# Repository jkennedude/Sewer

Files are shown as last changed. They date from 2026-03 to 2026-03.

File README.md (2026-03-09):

# Sewer
A guitar effects pedal, based on the Proco-Rat, with custom mods for use with Bass and noise reduction

Version 2 makes some incremental improvements:
- SMD Layout for most of the board
- Mix knob converted to additive opamp clean blend for ease of use and to prevent volume drop when turning up clean mix
- Bass Switch simplified and made internal
- Better fit and finish

Specifications:
- Designed for a Hammond 125B enclosure with top mounted jacks
- Power: 9V DC center negative, no battery support
- Support for external bypass board enabling true or buffered bypass
- Input impedance: 1MOhms or more
- Output impedance: ~1KOhm
- Buffered clean blend
- Switchable distortion bass boost changes how much bass is distorted
- Swichable clipping diodes (by default either standard 1N914 or turbo-rat style red LEDs)

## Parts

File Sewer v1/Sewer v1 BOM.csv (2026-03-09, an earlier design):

Id | Designator | Footprint | Quantity | Designation | Supplier and ref | Column1 | _1
1 | R_CLR | RES_0.25watt_L3.6mm_D1.6mm_P7.62mm_Horizontal | 1 | 4.7k
2 | R103,R102,R9,R1 | RES_0.25watt_L3.6mm_D1.6mm_P7.62mm_Horizontal | 4 | 1M
3 | D3,D4 | LED_D3.0mm | 2 | LED
4 | D2,D1 | D_DO-35_SOD27_P7.62mm_Horizontal | 2 | 1N914
5 | R10,R104,R105 | RES_0.25watt_L3.6mm_D1.6mm_P7.62mm_Horizontal | 3 | 10k
6 | C9 | C_Rect_L7.2mm_W2.5mm_P5.00mm_FKS2_FKP2_MKS2_MKP2 | 1 | 3n3
7 | C10,C1 | C_Rect_L7.2mm_W2.5mm_P5.00mm_FKS2_FKP2_MKS2_MKP2 | 2 | 22n
8 | R8 | RES_0.25watt_L3.6mm_D1.6mm_P7.62mm_Horizontal | 1 | 1k5
9 | Q102,Q101,Q1 | SOT-23_Handsoldering | 3 | J201
10 | C11 | C_Rect_L7.2mm_W7.2mm_P5.00mm_FKS2_FKP2_MKS2_MKP2 | 1 | 1u
11 | R2,R7 | RES_0.25watt_L3.6mm_D1.6mm_P7.62mm_Horizontal | 2 | 1k
12 | U1 | DIP-8_W7.62mm | 1 | OP07
13 | RV2 | POT_16MM | 1 | DIST A100k
14 | RV3 | POT_16MM | 1 | TONE A100k
15 | RV4 | POT_16MM | 1 | VOLUME A100k
16 | RV1 | POT_16MM | 1 | BLEND B100k
17 | SW1 | DPDT.LUGS | 1 | SW_DPDT_x2
18 | C203 | CP_Radial_D5.0mm_P2.50mm | 1 | 47u
19 | R6 | RES_0.25watt_L3.6mm_D1.6mm_P7.62mm_Horizontal | 1 | 270R
20 | C102,C202 | C_Rect_L7.2mm_W2.5mm_P5.00mm_FKS2_FKP2_MKS2_MKP2 | 2 | 100n
21 | C4 | CP_Radial_D5.0mm_P2.00mm | 1 | 2u2
22 | J2,J1 | SolderWire-0.25sqmm_1x04_P4.2mm_D0.65mm_OD1.7mm | 2 | Conn_01x04
23 | C3 | C_CERAMIC_DISC_D3.0mm_W1.6mm_P2.50mm | 1 | 100p
24 | R3,R201 | RES_0.25watt_L3.6mm_D1.6mm_P7.62mm_Horizontal | 2 | 47R
25 | R4,R5 | RES_0.25watt_L3.6mm_D1.6mm_P7.62mm_Horizontal | 2 | 560R
26 | R101 | RES_0.25watt_L3.6mm_D1.6mm_P7.62mm_Horizontal | 1 | 10M
27 | C7 | CP_Radial_D5.0mm_P2.50mm | 1 | 10u
28 | C2 | C_Rect_L7.2mm_W2.5mm_P5.00mm_FKS2_FKP2_MKS2_MKP2 | 1 | 1n
29 | C6,C8,C5 | CP_Radial_D5.0mm_P2.00mm | 3 | 4u7
30 | C101 | C_Rect_L7.2mm_W4.5mm_P5.00mm_FKS2_FKP2_MKS2_MKP2 | 1 | 470n
31 | C201 | CP_Radial_D5.0mm_P2.50mm | 1 | 100u
32 | R202,R203 | RES_0.25watt_L3.6mm_D1.6mm_P7.62mm_Horizontal | 2 | 100k
33 | SW2 | SW_SPDT | 1 | SW_SPDT

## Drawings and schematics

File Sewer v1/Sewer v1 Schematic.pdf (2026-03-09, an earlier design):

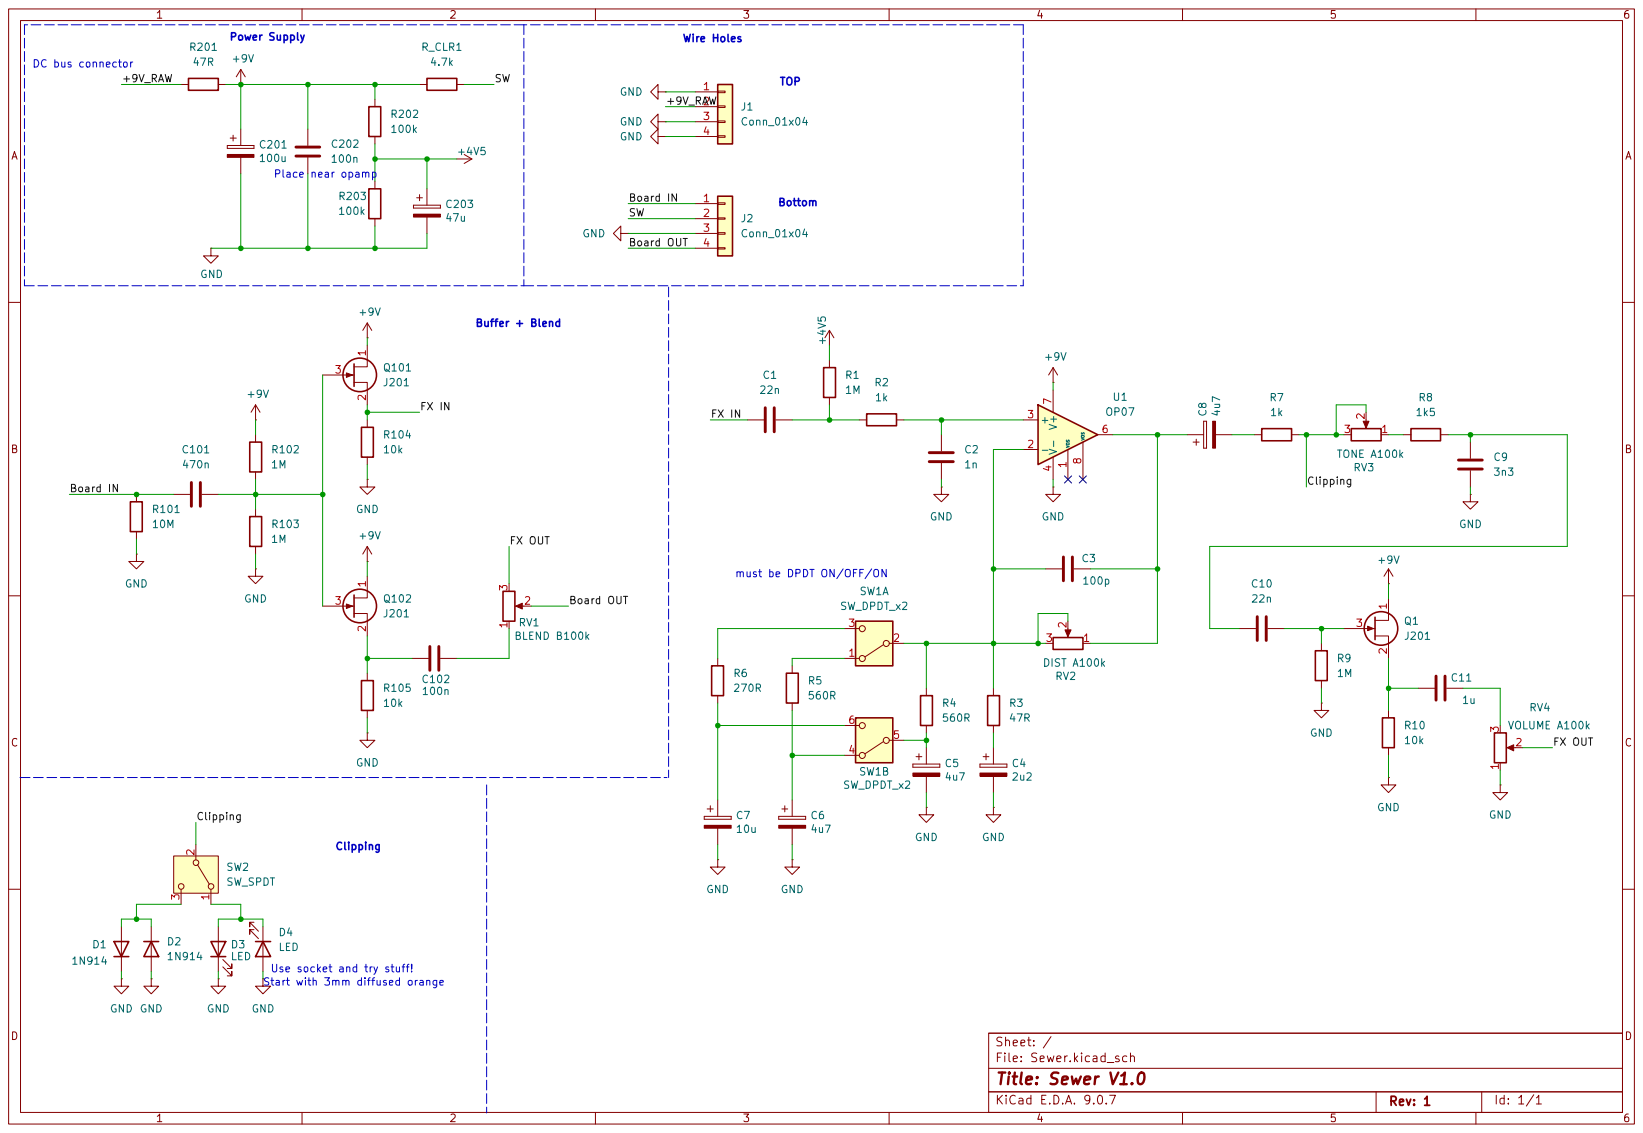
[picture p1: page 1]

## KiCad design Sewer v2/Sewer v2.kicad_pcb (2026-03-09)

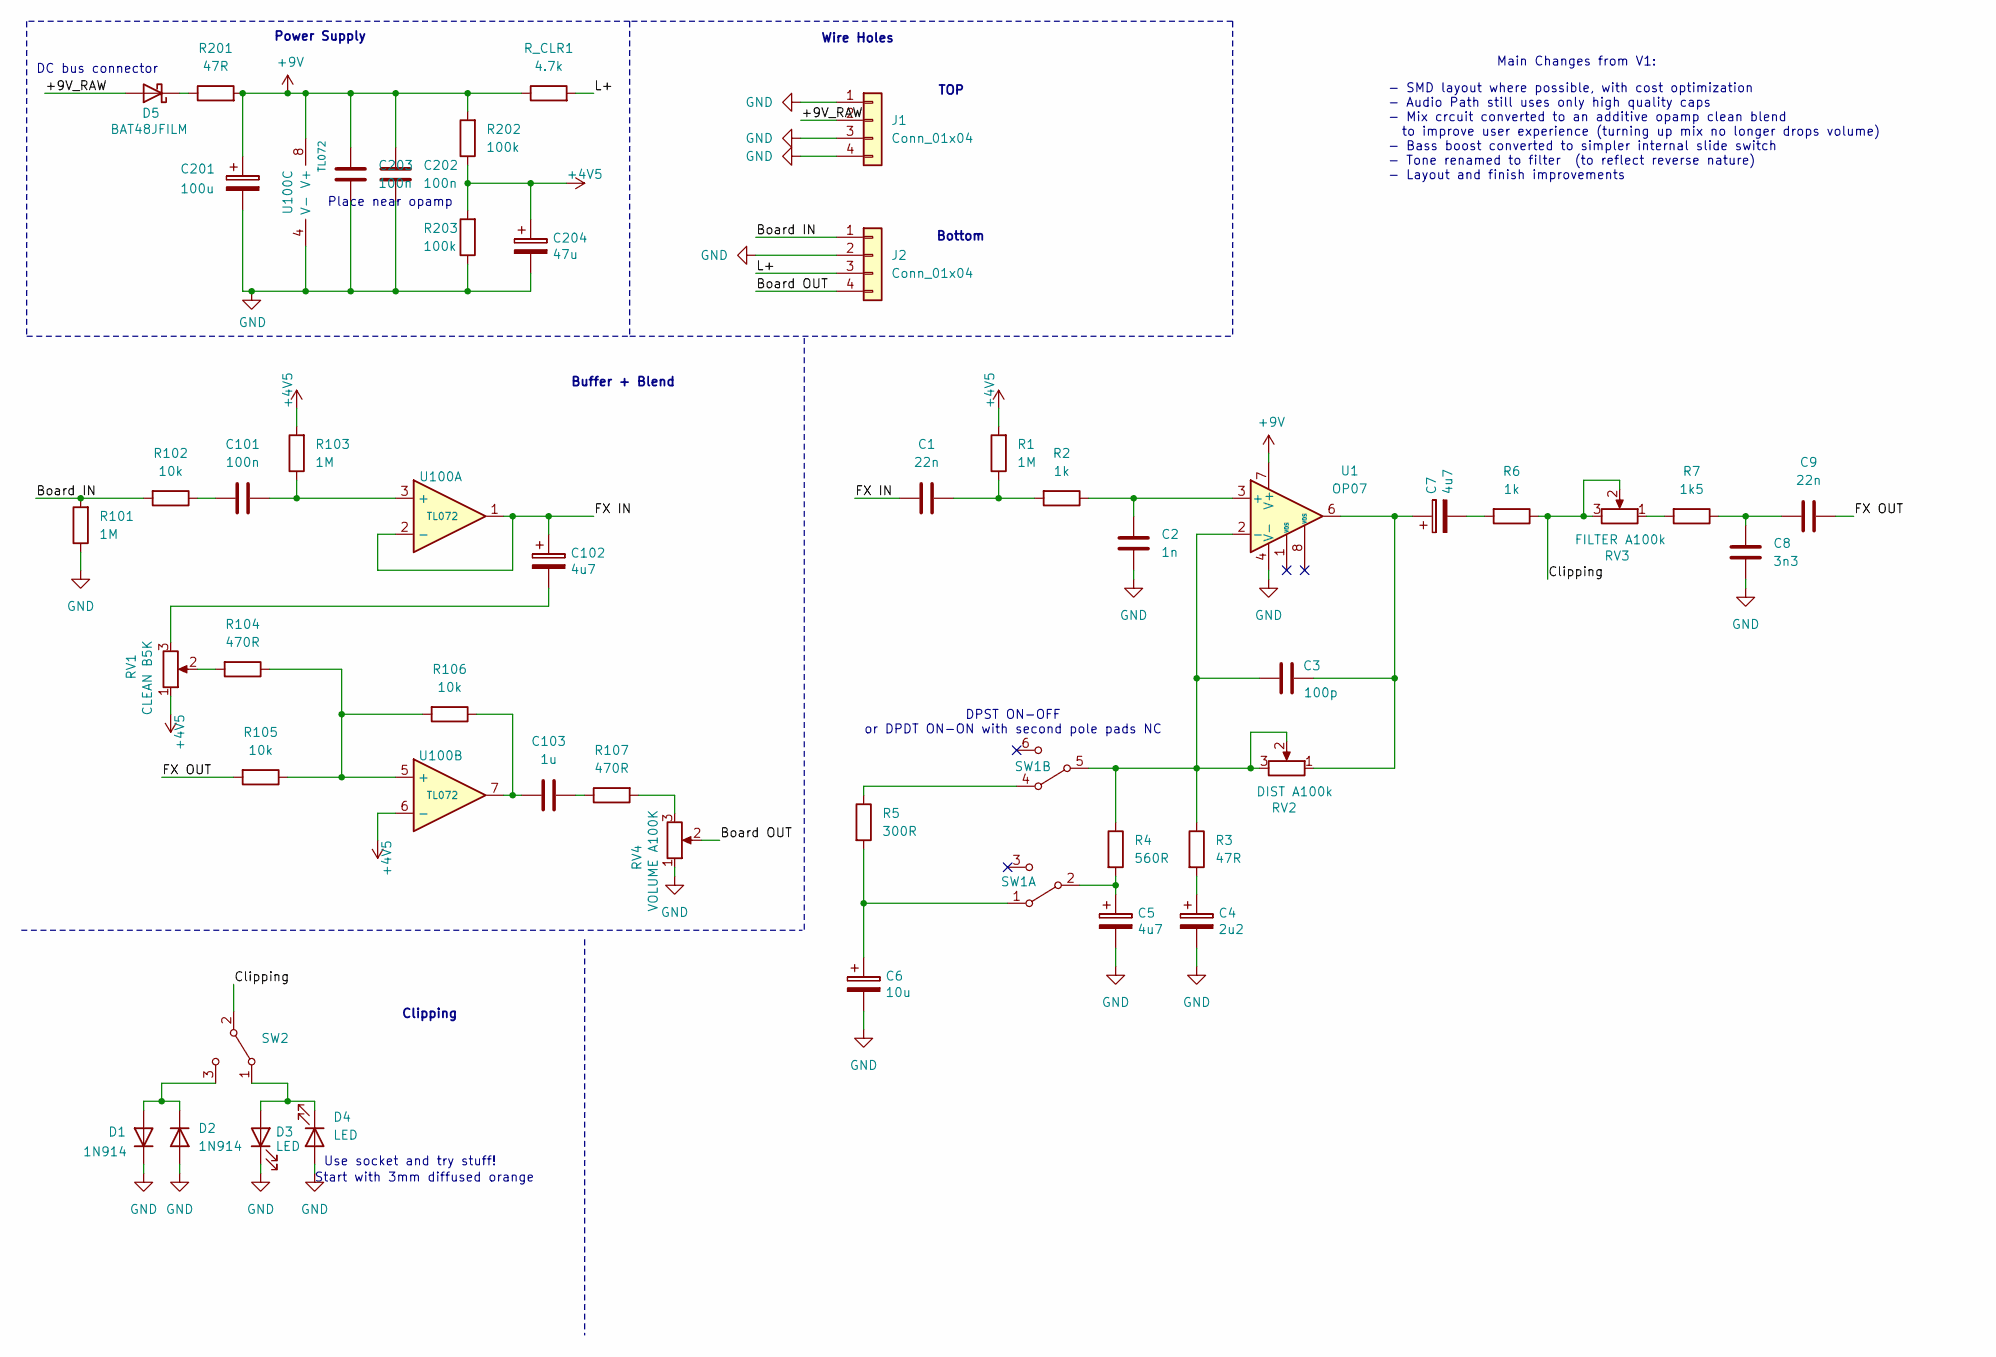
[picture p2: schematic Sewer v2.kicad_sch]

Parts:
C1, C9: 22n; TH_Film_Medium_2.5mm
C2: 1n; TH_Film_Medium_2.5mm
C3: 100p; SMD_Cap_0805; LCSC # C1790
C4: 2u2; SMD_Cap_D4; LCSC # C278511
C5, C7, C102: 4u7; SMD_Cap_D4; LCSC # C178620
C6: 10u; SMD_Cap_D4; LCSC # C178501
C8: 3n3; TH_Film_Medium_2.5mm
C101: 100n; TH_Film_Medium_2.5mm
C103: 1u; TH_Film_Thick_5mm
C201: 100u; TH_Cap_Lg_Radial_D7.5mm_P2.50mm
C202, C203: 100n; SMD_Cap_0805; LCSC # C28233
C204: 47u; TH_Cap_Med_Radial_D6.3mm_P2.50mm
D1, D2: 1N914; DO-35_P7.62mm
D3, D4: LED; LED_D3.0mm
D5: BAT48JFILM; D_SOD-323; LCSC # C2798199
J1, J2: Conn_01x04; SolderWire-0.25sqmm_1x04_P4.2mm_D0.65mm_OD1.7mm
R1, R101, R103: 1M; R_0805_2012Metric; LCSC # C17514
R2, R6: 1k; R_0805_2012Metric; LCSC # C17513
R3, R201: 47R; R_0805_2012Metric; LCSC # C17714
R4: 560R; R_0805_2012Metric; LCSC # C28636
R5: 300R; R_0805_2012Metric; LCSC # C17617
R7: 1k5; R_0805_2012Metric; LCSC # C4310
R102, R105, R106: 10k; R_0805_2012Metric; LCSC # C17414
R104, R107: 470R; R_0805_2012Metric; LCSC # C17710
R202, R203: 100k; R_1206_3216Metric; LCSC # C17900
RV1: CLEAN B5K; Pot_16mm
RV2: DIST A100k; Pot_16mm
RV3: FILTER A100k; Pot_16mm
RV4: VOLUME A100K; Pot_16mm
R_CLR1: 4.7k; R_1206_3216Metric; LCSC # C17936
SW1: DPDT_SLIDE_JLC_C108742; LCSC # C108742
SW2: Mini Switch SPDT
U1: OP07; SOIC-8_3.9x4.9mm_P1.27mm; LCSC # C7433
U100: TL072; SOIC-8_3.9x4.9mm_P1.27mm; LCSC # C6961

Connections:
+4V5: C204.1, R1.2, R103.2, R202.1, R203.2, RV1.1, U100.6 (-)
+9V: C201.1, C202.1, C203.1, R201.2, R202.2, R_CLR1.1, U1.7 (V+), U100.8 (V+)
/+9V_RAW: D5.2 (A), J1.2
/Board IN: J2.1, R101.2, R102.2
/Board OUT: J2.4, RV4.2
/Clipping: R6.1, RV3.2, RV3.3, SW2.2
/FX IN: C1.1, C102.1, U100.1, U100.2 (-)
/FX OUT: C9.1, R105.2
/L+: J2.3, R_CLR1.2
GND: C2.1, C4.2, C5.2, C6.2, C8.1, C201.2, C202.2, C203.2, C204.2, D1.1 (K), D2.2 (A), D3.1 (K), D4.2 (A), J1.1, J1.3, J1.4, J2.2, R101.1, R203.1, RV4.1, U1.4 (V-), U100.4 (V-)
unnamed: C1.2, R1.1, R2.2
unnamed: C3.1, C7.1, RV2.1, U1.6
unnamed: C4.1, R3.2
unnamed: C5.1, R4.2, SW1.2
unnamed: C6.1, R5.2, SW1.1
unnamed: C7.2, R6.2
unnamed: C8.2, C9.2, R7.1
unnamed: C101.1, R102.1
unnamed: C102.2, RV1.3
unnamed: C103.1, R107.1
unnamed: C103.2, R106.1, U100.7
unnamed: D1.2 (A), D2.1 (K), SW2.3
unnamed: D3.2 (A), D4.1 (K), SW2.1
unnamed: D5.1 (K), R201.1
unnamed: R5.1, SW1.4
unnamed: R7.2, RV3.1
unnamed: R104.2, RV1.2
unnamed: R107.2, RV4.3
unnamed: C2.2, R2.1, U1.3 (+)
unnamed: C3.2, R3.1, R4.1, RV2.2, RV2.3, SW1.5, U1.2 (-)
unnamed: C101.2, R103.1, U100.3 (+)
unnamed: R104.1, R105.1, R106.2, U100.5 (+)

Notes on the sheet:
Power Supply
- SMD layout where possible, with cost optimization - Audio Path still uses only high quality caps - Mix crcuit converted to an additive opamp clean blend to improve user experience (turning up mix no longer drops volume) - Bass boost converted to simpler internal slide switch - Tone renamed to fil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
Main Changes from V1:
Bottom
Buffer + Blend
Use socket and try stuff!
DPST ON-OFF or DPDT ON-ON with second pole pads NC
Start with 3mm diffused orange
DC bus connector
TOP
Wire Holes
Place near opamp
Clipping

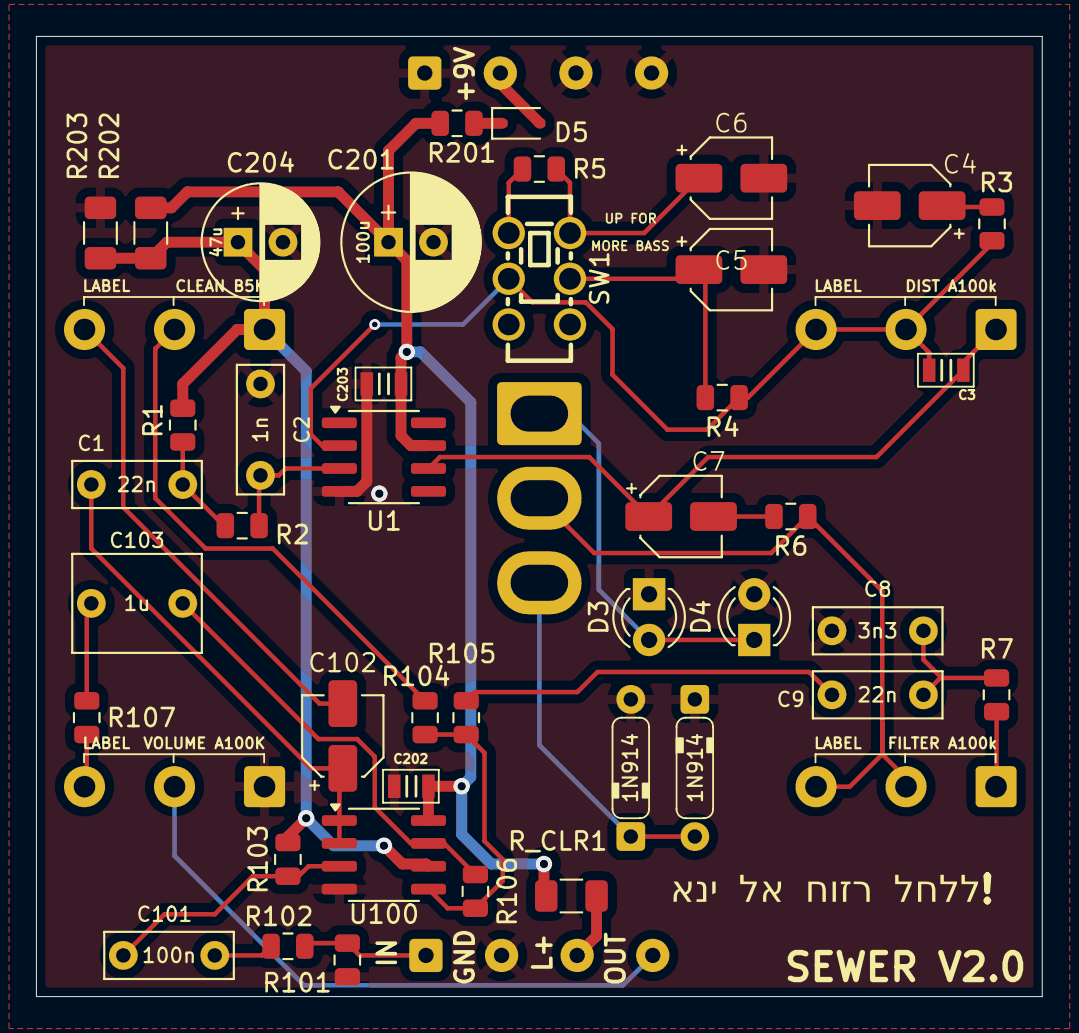
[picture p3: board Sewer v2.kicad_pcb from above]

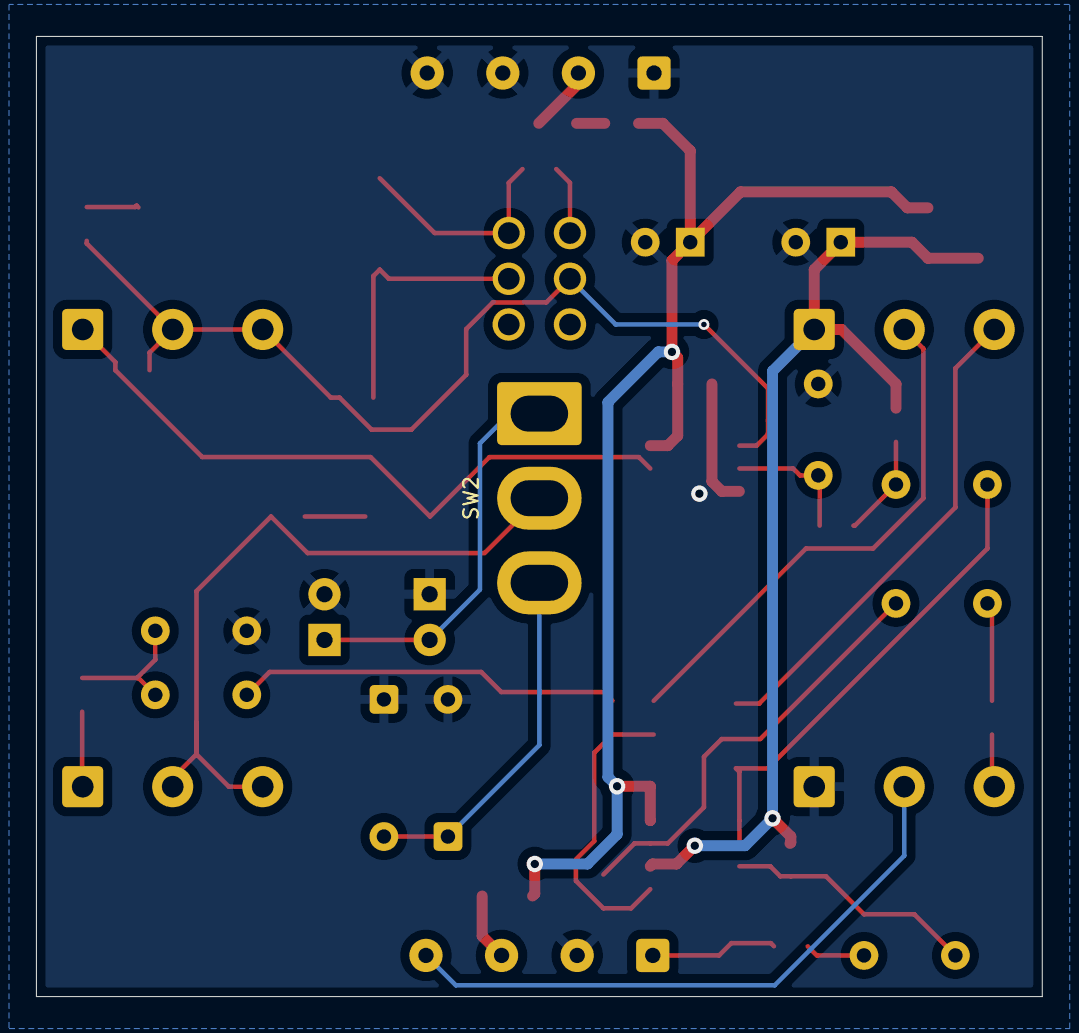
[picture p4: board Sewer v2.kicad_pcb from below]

Board: 2 copper layers, 55.9 x 53.3 mm, 49 parts (5 on the bottom side), 32 nets.

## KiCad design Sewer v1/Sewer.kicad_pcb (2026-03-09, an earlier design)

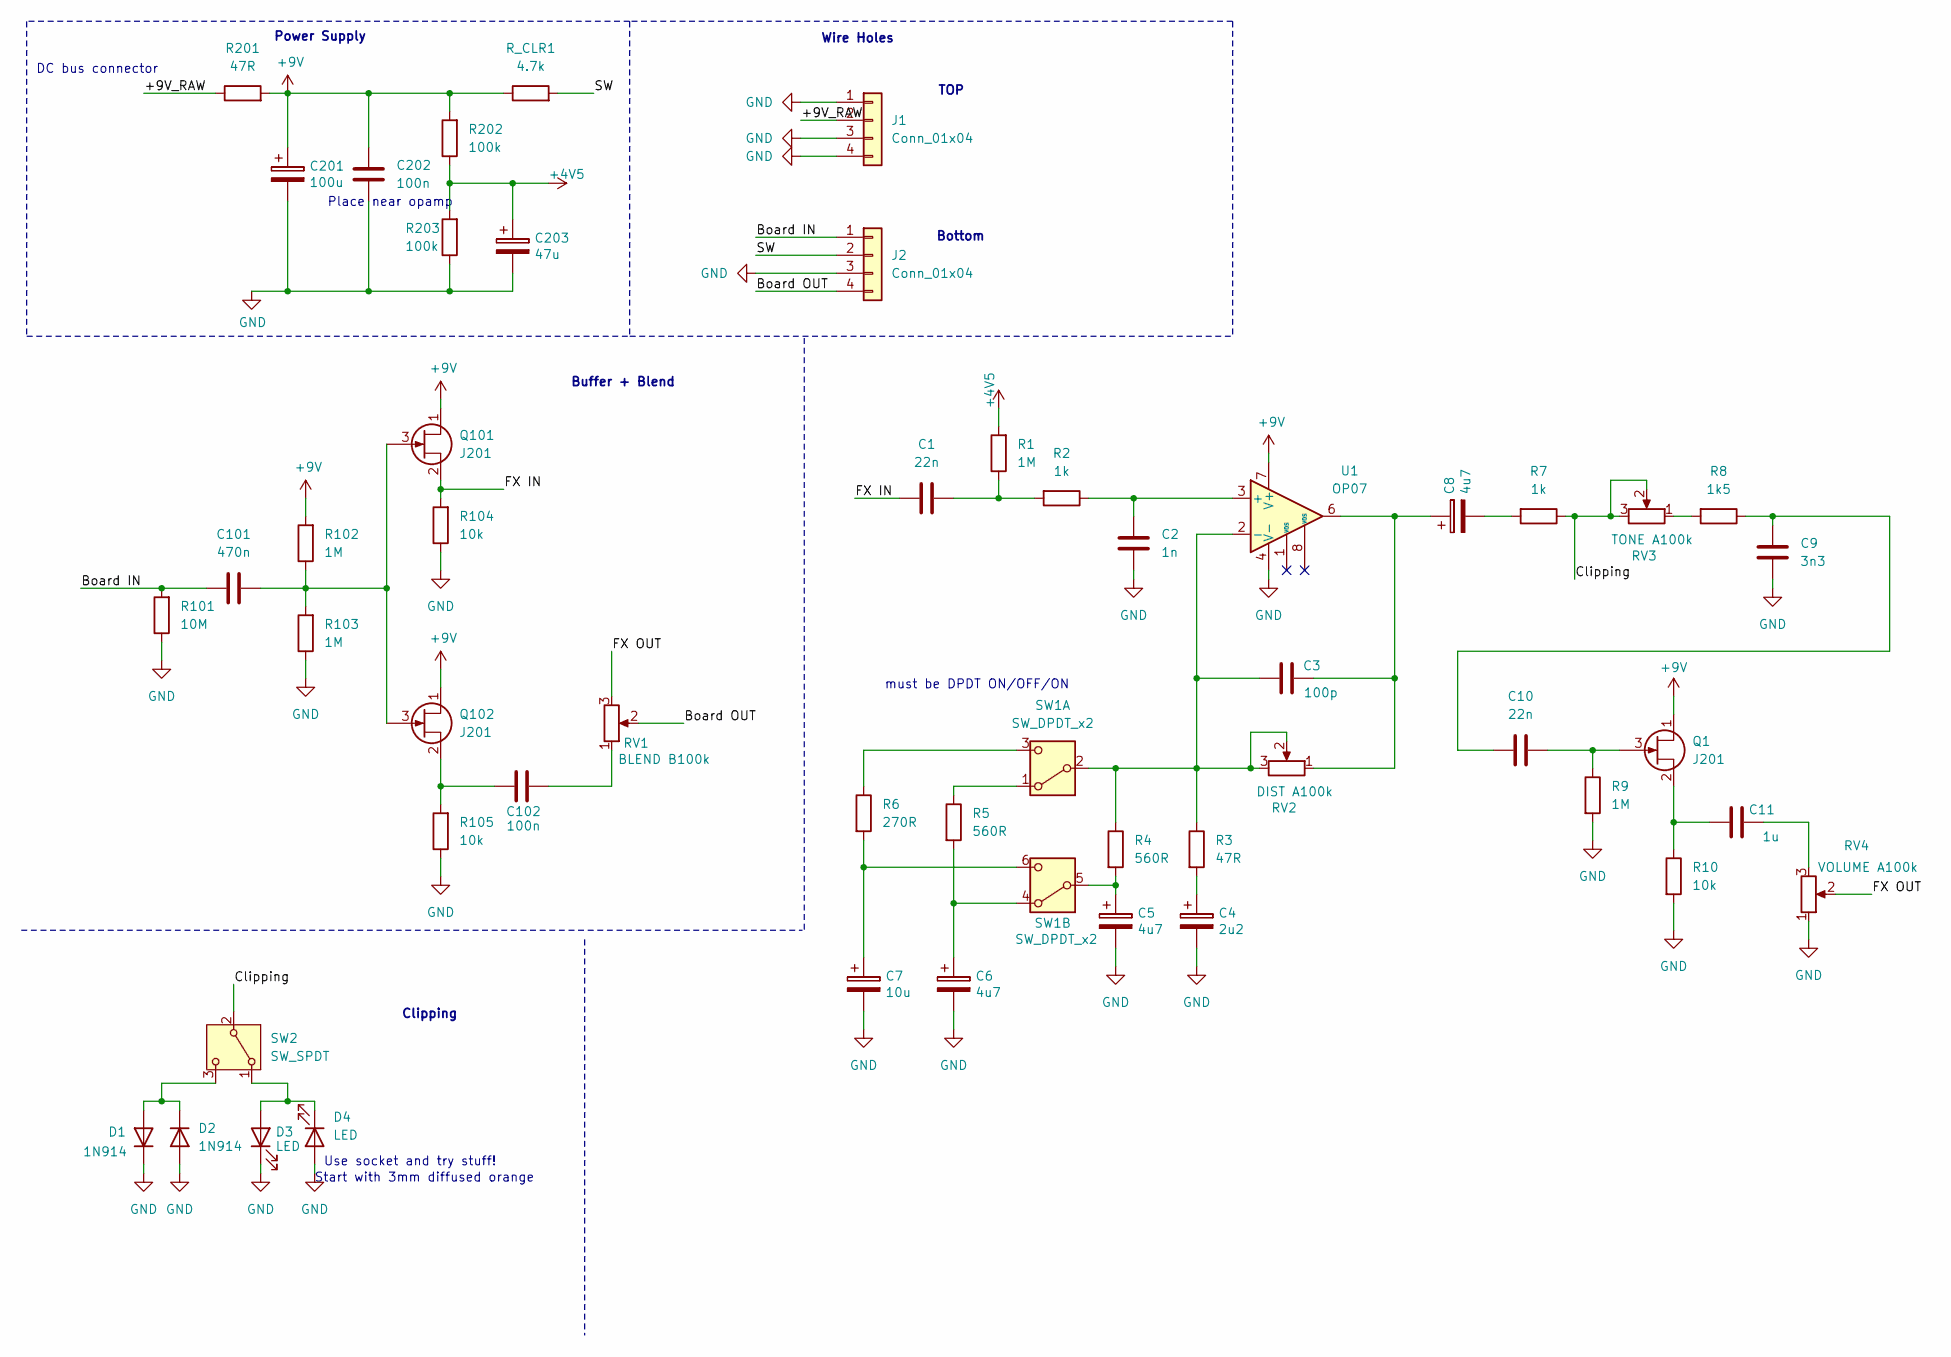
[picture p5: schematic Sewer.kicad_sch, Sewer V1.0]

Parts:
C1, C10: 22n; C_Rect_L7.2mm_W2.5mm_P5.00mm_FKS2_FKP2_MKS2_MKP2
C2: 1n; C_Rect_L7.2mm_W2.5mm_P5.00mm_FKS2_FKP2_MKS2_MKP2
C3: 100p; C_CERAMIC_DISC_D3.0mm_W1.6mm_P2.50mm
C4: 2u2; CP_Radial_D5.0mm_P2.00mm
C5, C6, C8: 4u7; CP_Radial_D5.0mm_P2.00mm
C7: 10u; CP_Radial_D5.0mm_P2.50mm
C9: 3n3; C_Rect_L7.2mm_W2.5mm_P5.00mm_FKS2_FKP2_MKS2_MKP2
C11: 1u; C_Rect_L7.2mm_W7.2mm_P5.00mm_FKS2_FKP2_MKS2_MKP2
C101: 470n; C_Rect_L7.2mm_W4.5mm_P5.00mm_FKS2_FKP2_MKS2_MKP2
C102, C202: 100n; C_Rect_L7.2mm_W2.5mm_P5.00mm_FKS2_FKP2_MKS2_MKP2
C201: 100u; CP_Radial_D5.0mm_P2.50mm
C203: 47u; CP_Radial_D5.0mm_P2.50mm
D1, D2: 1N914; D_DO-35_SOD27_P7.62mm_Horizontal
D3, D4: LED; LED_D3.0mm
J1, J2: Conn_01x04; SolderWire-0.25sqmm_1x04_P4.2mm_D0.65mm_OD1.7mm
Q1, Q101, Q102: J201; SOT-23_Handsoldering
R1, R9, R102, R103: 1M; RES_0.25watt_L3.6mm_D1.6mm_P7.62mm_Horizontal
R2, R7: 1k; RES_0.25watt_L3.6mm_D1.6mm_P7.62mm_Horizontal
R3, R201: 47R; RES_0.25watt_L3.6mm_D1.6mm_P7.62mm_Horizontal
R4, R5: 560R; RES_0.25watt_L3.6mm_D1.6mm_P7.62mm_Horizontal
R6: 270R; RES_0.25watt_L3.6mm_D1.6mm_P7.62mm_Horizontal
R8: 1k5; RES_0.25watt_L3.6mm_D1.6mm_P7.62mm_Horizontal
R10, R104, R105: 10k; RES_0.25watt_L3.6mm_D1.6mm_P7.62mm_Horizontal
R101: 10M; RES_0.25watt_L3.6mm_D1.6mm_P7.62mm_Horizontal
R202, R203: 100k; RES_0.25watt_L3.6mm_D1.6mm_P7.62mm_Horizontal
RV1: BLEND B100k; POT_16MM
RV2: DIST A100k; POT_16MM
RV3: TONE A100k; POT_16MM
RV4: VOLUME A100k; POT_16MM
R_CLR1: 4.7k; RES_0.25watt_L3.6mm_D1.6mm_P7.62mm_Horizontal
SW1: SW_DPDT_x2; DPDT.LUGS
SW2: SW_SPDT
U1: OP07; DIP-8_W7.62mm

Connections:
+4V5: C203.1, R1.2, R202.1, R203.2
+9V: C201.1, C202.1, Q1.1 (D), Q101.1 (D), Q102.1 (D), R102.2, R201.2, R202.2, R_CLR1.1, U1.7 (V+); also elsewhere on the board
/+9V_RAW: J1.2, R201.1
/Board IN: C101.1, J2.1, R101.2
/Board OUT: J2.4, RV1.2
/Clipping: R7.1, RV3.2, RV3.3, SW2.2 (B)
/FX IN: C1.1, Q101.2 (S), R104.2
/FX OUT: RV1.3, RV4.2
/SW: J2.2, R_CLR1.2; also elsewhere on the board
GND: C2.1, C4.2, C5.2, C6.2, C7.2, C9.1, C201.2, C202.2, C203.2, D1.1 (K), D2.2 (A), D3.1 (K), D4.2 (A), J1.1, J1.3, J1.4, J2.3, R9.2, R10.2, R101.1, R103.1, R104.1, R105.1, R203.1, RV4.1, U1.4 (V-)
unnamed: C1.2, R1.1, R2.2
unnamed: C3.1, C8.1, RV2.1, U1.6
unnamed: C4.1, R3.2
unnamed: C8.2, R7.2
unnamed: C9.2, C10.2, R8.1
unnamed: C11.1, RV4.3
unnamed: C102.2, RV1.1
unnamed: D1.2 (A), D2.1 (K), SW2.3 (C)
unnamed: D3.2 (A), D4.1 (K), SW2.1 (A)
unnamed: C10.1, Q1.3 (G), R9.1
unnamed: C11.2, Q1.2 (S), R10.1
unnamed: C101.2, Q101.3 (G), Q102.3 (G), R102.1, R103.2
unnamed: C102.1, Q102.2 (S), R105.2
unnamed: R8.2, RV3.1
unnamed: R5.1, SW1.1 (A)
unnamed: C3.2, R3.1, R4.1, RV2.2, RV2.3, SW1.2 (B), U1.2 (-)
unnamed: R6.1, SW1.3 (C)
unnamed: C6.1, R5.2, SW1.4 (A)
unnamed: C5.1, R4.2, SW1.5 (B)
unnamed: C7.1, R6.2, SW1.6 (C)
unnamed: C2.2, R2.1, U1.3 (+)

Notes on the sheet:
DC bus connector
Place near opamp
Use socket and try stuff!
Wire Holes
Buffer + Blend
Start with 3mm diffused orange
Bottom
Power Supply
Clipping
TOP
must be DPDT ON/OFF/ON

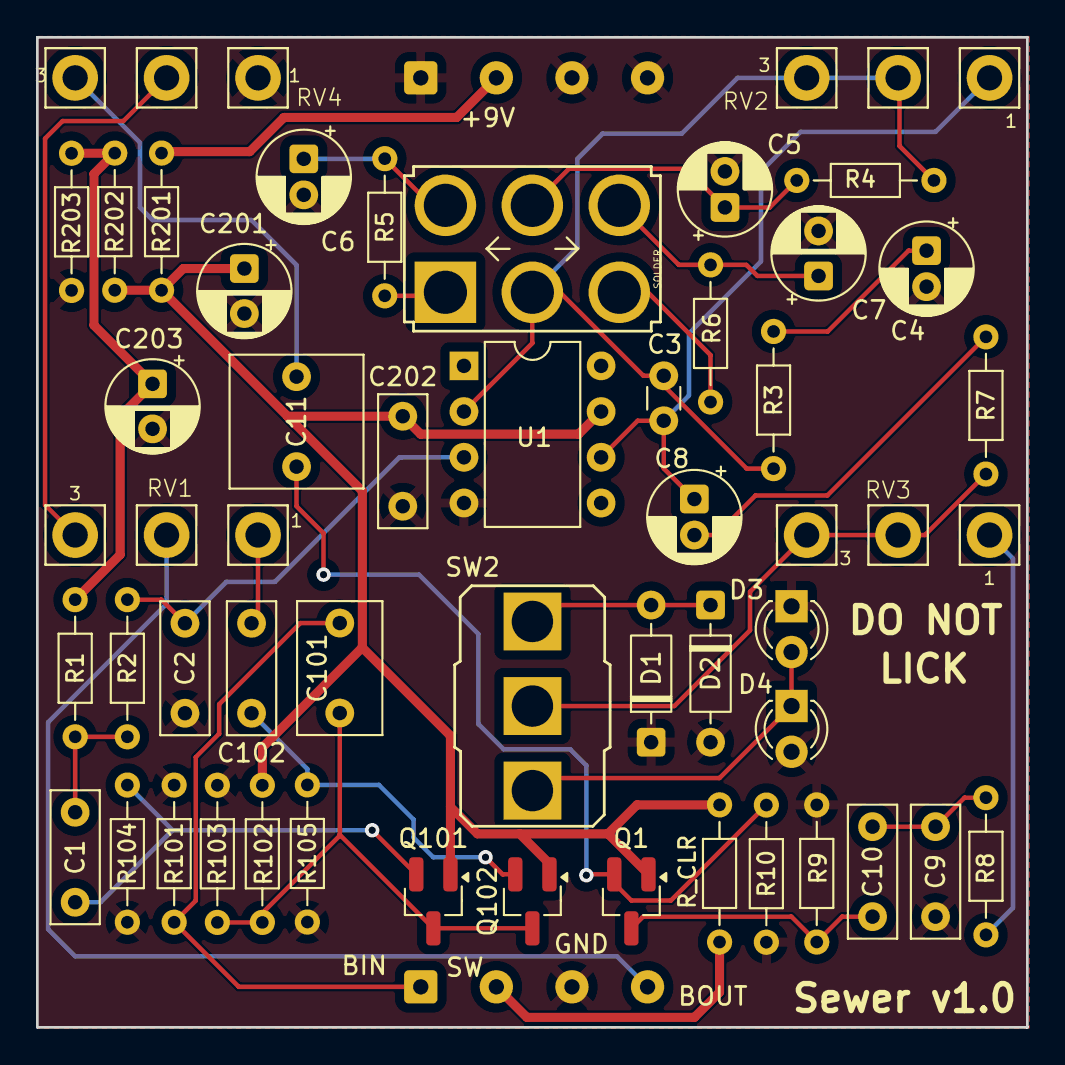
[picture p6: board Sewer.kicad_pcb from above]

Board: 2 copper layers, 55.0 x 55.0 mm, 51 parts (0 on the bottom side), 31 nets.

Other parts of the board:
R_CLR: 4.7k; RES_0.25watt_L3.6mm_D1.6mm_P7.62mm_Horizontal

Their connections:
+9V: R_CLR.1; also elsewhere on the board
/SW: R_CLR.2; also elsewhere on the board

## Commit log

2026-03-09 Add v1 files
    [Sewer v1 BOM.csv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]
2026-03-09 Add v2
    [Sewer v2.kicad_pcb, Sewer v2.kicad_sch]
